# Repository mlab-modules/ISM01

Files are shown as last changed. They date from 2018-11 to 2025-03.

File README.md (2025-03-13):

# ISM01 - Si1060 EZRadioPRO Transceiver

The ISM01 is a high-performance wireless transceiver designed for long-distance data transmission. The module is based on the [Si4463 chip](https://www.silabs.com/wireless/proprietary/ezradiopro-sub-ghz-ics/device.si4463?tab=specs) from Silicon Labs, which is part of the EZRadioPRO family. With its wide frequency range and output power, it is ideal for robust and reliable wireless communication applications. 

ISM01A can operate on the open 433 or 868 MHz frequencies, which are popular in many applications.

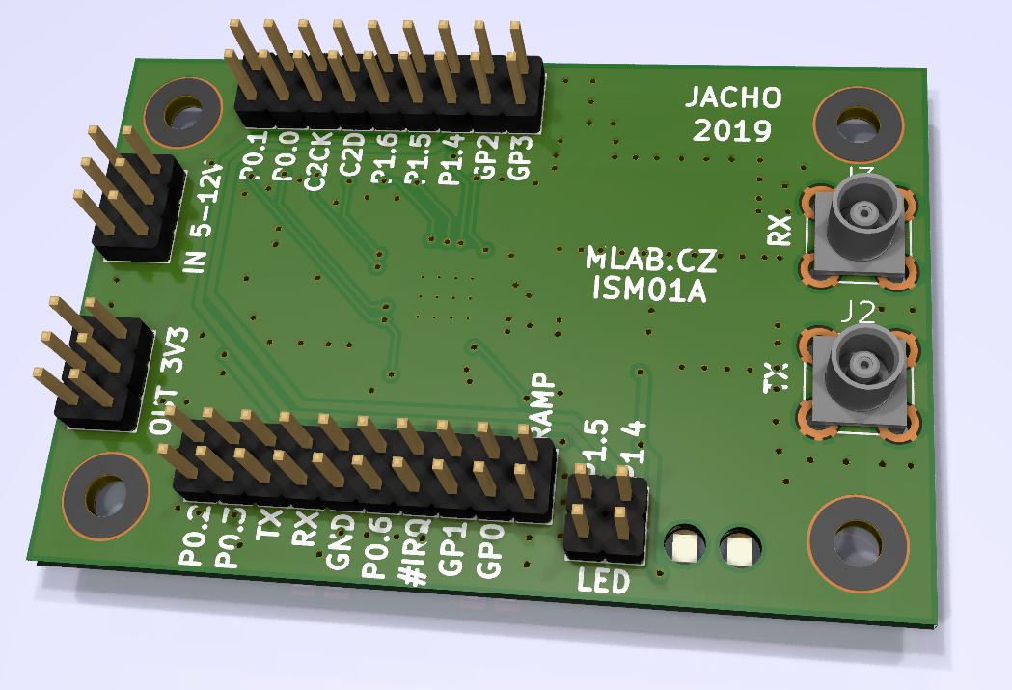
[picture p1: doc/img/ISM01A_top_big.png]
Top view on ISM01A


## Parameters

- Based on the Si1060 microcontroller integrating the Si4463 transceiver
- Chip frequency range: 142 to 1050 MHz, with the ability to operate on the open 433 or 868 MHz frequencies
- Chip output power: -20 to 20 dBm
- The Si4463 chip includes a programmable block capable of controlling radio settings and supports the SPI interface
- Power supply: 5-12V with integrated 3.3V stabilizer
- Communication: UART, SPI, GPIO
- Accessible GPIO signals directly from the transceiver
- Status indication: Two LEDs controlled from the Si chip
- Antenna connectors: MCX for RX and TX antennas. For bidirectional communication with a single antenna, connecting the [RFSWITCH module](www.mlab.cz/module/RFSWITCH01/) is recommended, which serves as an RF switch and enables MIMO 2x2 support. ISM01A can control the RFSWITCH module through GPIO pins

## Possible Applications

The MLAB ISM01A module with the Si4463 transceiver is suitable for various applications. It can be used in areas such as:

- **Remote Control**: The module can be used for wireless control of various devices, such as drones, RC cars, or home automation.
- **Data Links**: With prepared firmware, the module can function as a [SiK data communication link](https://ardupilot.org/copter/docs/common-sik-telemetry-radio.html), which can transmit [MAVLink packets](https://mavlink.io/en/). MAVLink is a protocol designed for communication with unmanned vehicles and is supported by the most widespread autopilots Ardupilot and PX4. This is ideal for applications that require wireless data transmission.
- **Wireless Sensor Networks**: The module can be used to create wireless sensor networks in IoT applications.

> Based on this module, the company [ThunderFly](https://www.thunderfly.cz) has developed a [TFSIK01](https://docs.thunderfly.cz/avionics/TFSIK01/) optimized for use on drones, which combines this ISM01A module, [RFSWITCH01](https://mlab.cz/module/RFSWITCH01/), and additional RF filters and LNA. More information about this TFSIK01 module can be found [here](https://github.com/ThunderFly-aerospace/TFSIK01/).

## Links to Related Resources

- [Silicon Labs Si4463 Product Page](https://www.silabs.com/wireless/proprietary/ezradiopro-sub-ghz-ics/device.si4463?tab=specs)
- [Si4463 Datasheet](https://www.silabs.com/documents/public/data-sheets/Si4464-63-61-60.pdf)
- [MavLink Protocol](https://mavlink.io/en/)
- [SiK Radio](https://ardupilot.org/copter/docs/common-sik-telemetry-radio.html)
- [EZRADioPRO Family](https://www.silabs.com/wireless/proprietary/ezradiopro-sub-ghz-ics)
- [TFSIK01 Module by ThunderFly](https://github.com/ThunderFly-aerospace/TFSIK01/)

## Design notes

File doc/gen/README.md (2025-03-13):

# PCB

Board size: 60.45x40.13 mm (2.38x1.58 inches)

- This is the size of the rectangle that contains the board
- Thickness: 1.6 mm (63 mils)
- Material: FR4
- Finish: HAL
- Layers: 2
- Copper thickness: 35 µm

Solder mask: TOP / BOTTOM

- Color: Green

Silk screen: TOP / BOTTOM

- Color: White

# Important sizes

Clearance: 0.2 mm (8 mils)

Track width: 0.2 mm (8 mils)

- By design rules: 0.2 mm (8 mils)

Drill: 0.3 mm (12 mils)

- Vias: 0.5 mm (20 mils) [Design: 0.4 mm (16 mils)]
- Pads: 0.3 mm (12 mils)
- The above values are real drill sizes, they add 0.1 mm (4 mils) to plated holes (PTH)

Via: 0.8/0.4 mm (31/16 mils)

- By design rules: 0.4/0.3 mm (16/12 mils)
- Micro via: yes [0.2/0.1 mm (8/4 mils)]
- Buried/blind via: yes
- Total: 129 (thru: 129 buried/blind: 0 micro: 0)

Outer Annular Ring: 0.1 mm (4 mils)

- By design rules: 0.1 mm (4 mils)

Eurocircuits class: 6D
- Using min drill 0.25 mm for an OAR of 0.13 mm

# General stats

Components count: (SMD/THT)

- Top: 0/29 (THT)
- Bottom: 67/2 (SMD + THT)

Defined tracks:

- 0.2 mm (8 mils)
- 0.3 mm (12 mils)
- 0.4 mm (16 mils)
- 0.5 mm (20 mils)
- 0.5 mm (20 mils)
- 0.6 mm (24 mils)
- 0.8 mm (31 mils)
- 0.86 mm (34 mils)

Used tracks:

- 0.2 mm (8 mils) (194) defined: yes
- 0.3 mm (12 mils) (16) defined: yes
- 0.5 mm (20 mils) (175) defined: yes
- 0.86 mm (34 mils) (48) defined: yes

Defined vias:

- 0.8/0.4 mm (31/16 mils)

Used vias:

- 0.8/0.4 mm (31/16 mils) (Count: 129, Aspect: 2.0 A) defined: yes

Holes (excluding vias):

- 0.2 mm (8 mils) (12)
- 0.89 mm (35 mils) (54)
- 1.5 mm (59 mils) (2)
- 1.7 mm (67 mils) (8)
- 2.7 mm (106 mils) (2)
- 3.0 mm (118 mils) (4)

Oval holes:

Drill tools (including vias and computing adjusts and rounding):

- 0.3 mm (12 mils) (12)
- 0.5 mm (20 mils) (129)
- 1.0 mm (39 mils) (54)
- 1.6 mm (63 mils) (2)
- 1.8 mm (71 mils) (8)
- 2.7 mm (106 mils) (2)
- 3.1 mm (122 mils) (4)

Solder paste stats:

Using a paste with 87.75 % alloy, that has an specific gravity for the alloy of 7.4 g/cm³
and 1.0 g/cm³ for the flux. This paste has an specific gravity of  4.15 g/cm³.

The stencil thickness is  0.12 mm.

| Side | Pads with paste | Area [mm²] | Paste [g] |
|---|---|---|---|
| Total  | 185 | 208.88 | 1.04 |

Note: this is just an approximation to the theoretical value. Margins of the solder mask and waste aren't computed.

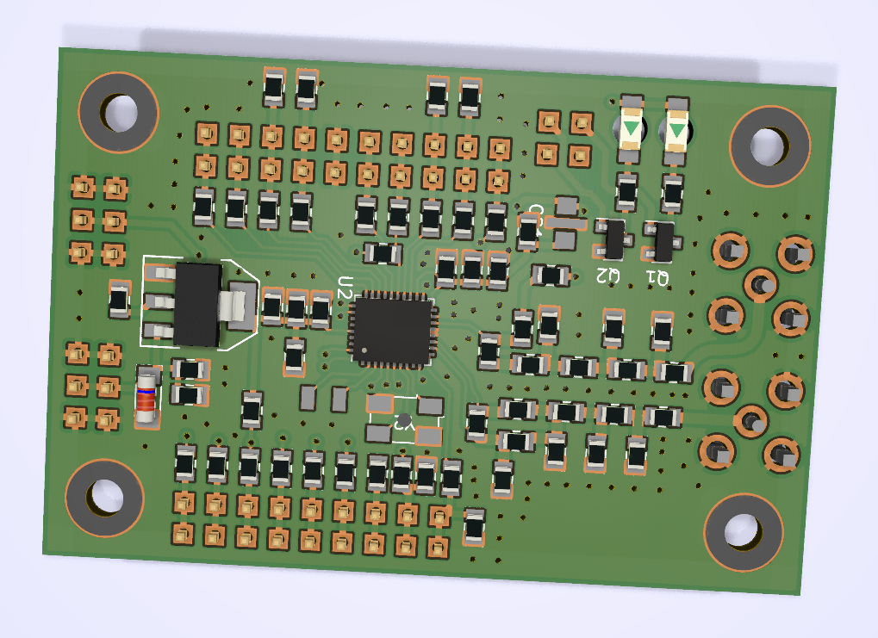
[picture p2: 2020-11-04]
doc/img/ISM01A_bot_big.png

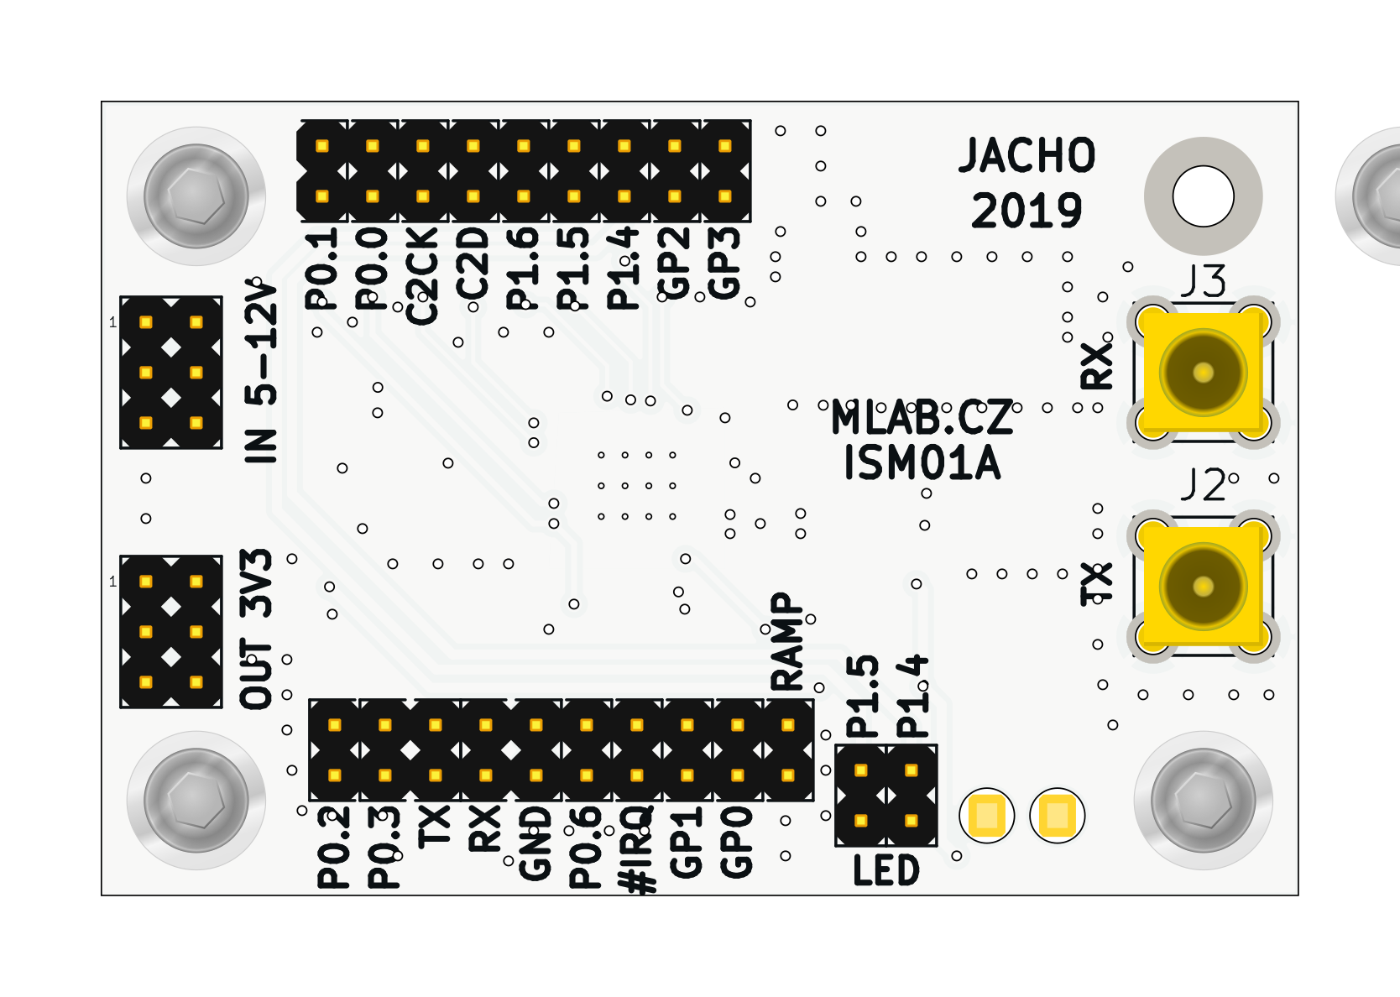
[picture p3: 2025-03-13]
doc/gen/img/ISM01-top.png

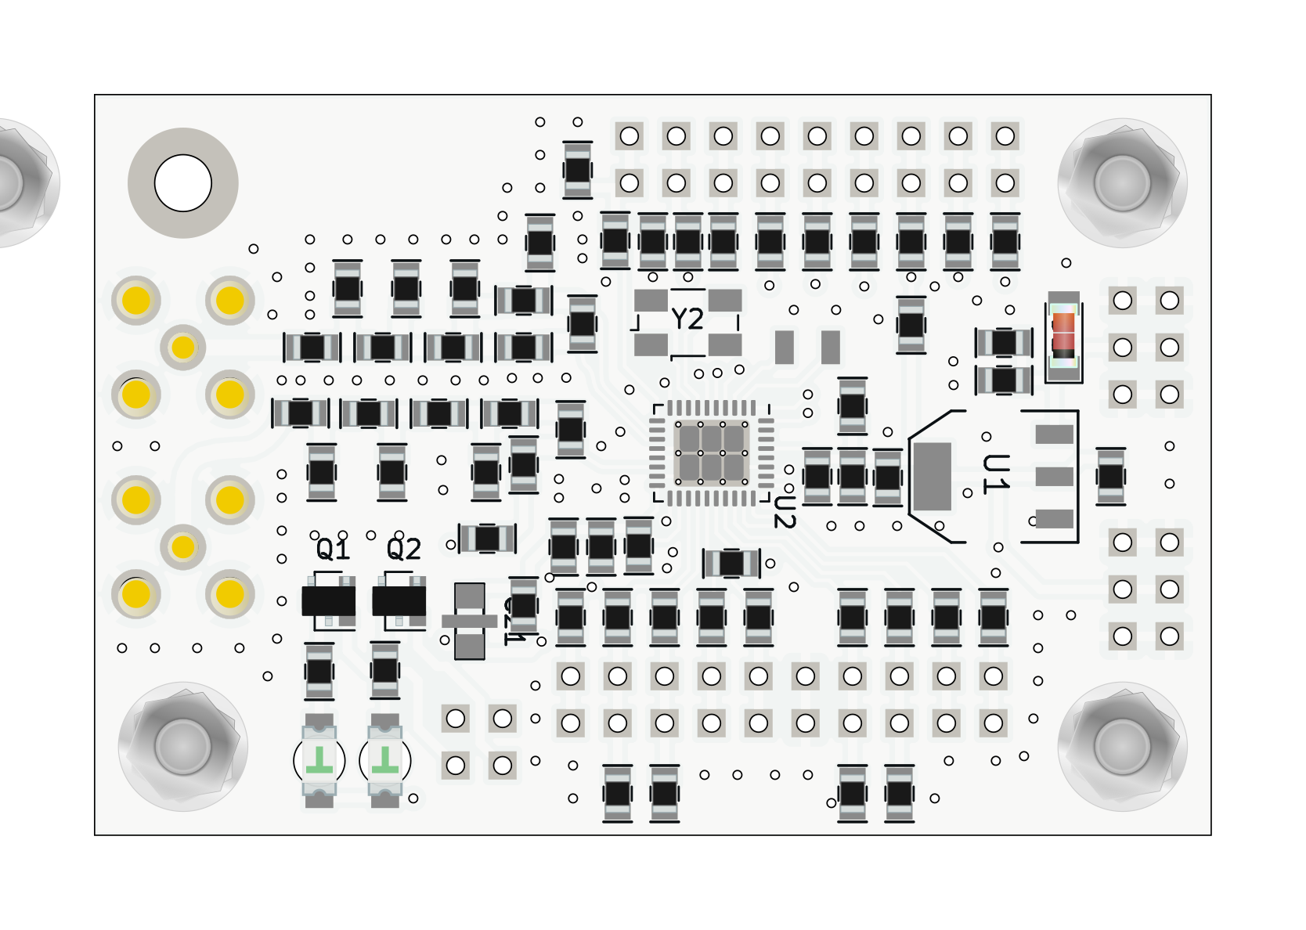
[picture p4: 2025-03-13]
doc/gen/img/ISM01-bottom.png

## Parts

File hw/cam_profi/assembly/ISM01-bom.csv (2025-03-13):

Component | Description | Part | References | Value | Footprint | Quantity Per PCB | Datasheet | ust_id
1 |  | C_Small | C12 | 2.7pF | SMD-0805 | 1 |  | 5c70984712875079b91f8b28
2 |  | C_Small | C13 | 5.1pF | SMD-0805 | 1 |  | 5c70984812875079b91f8ba2
3 |  | C_Small | C4C6 | 6.8pf | SMD-0805 | 2 |  | 5c70984712875079b91f8b2e
4 |  | C_Small | C7C8 | 15pF | SMD-0805 | 2 |  | 5c70984712875079b91f8b32
5 |  | C_Small | C15 | 33pF | SMD-0805 | 1 |  | 5c70984712875079b91f8b37
6 |  | C_Small | C9C10C11 | 8,2pF | SMD-0805 | 3 |  | 5c70984712875079b91f8b2f
7 |  | C_Small | C17 | 100pF | SMD-0805 | 1 |  | 5c70984712875079b91f8b3b
8 |  | C_Small | C14C22C23C25C26C27C28 | 10nF | SMD-0805 | 7 |  | 5c70984712875079b91f8b49
9 |  | C_Small | C2C16C19 | 100nF | SMD-0805 | 3 |  | 5c70984712875079b91f8b4c
10 |  | C_Small | C1C3C5C18C20 | 10uF | SMD-0805 | 5 |  | 5c70984812875079b91f8bbd
11 |  | EMI_Filter_C | C21 | NFM21PC105 | FIR1 | 1 | http://www.murata.com/~/media/webrenewal/support/library/catalog/products/emc/emifil/c31e.ashx?la=en-gb
12 |  | LED | D3 | GREEN | LED_1206 | 1 |  | 5c70984412875079b91f8895
13 |  | D_ZENER | D1 | M4 | Diode-MiniMELF_Standard | 1 |  | 5c70984512875079b91f88ac
14 |  | LED | D2 | RED | LED_1206 | 1 |  | 5c70984412875079b91f8896
15 |  | HEADER_1x02 | J24J25 | HEADER_1x02 | Straight_1x02 | 2
16 |  | HEADER_2x01_PARALLEL | J6J7J8J9J10J11J12J13J14J15J16J17J18J19J20J21J22J23J26 | HEADER_2x01_PARALLEL | Straight_2x01 | 19
17 |  | JUMP_3X2 | J1J4 | JUMP_3X2 | Straight_2x03 | 2
18 |  | SMA | J2J3 | SMA | SMA6251A13G50 | 2 |  | 5c70984412875079b91f87ac
19 |  | L_Small | L1L2 | 0R | SMD-0805 | 2 |  | 5c70984512875079b91f896b
20 |  | L_Small | L3L4L5L6 | 18nH | SMD-0805 | 4 |  | 5c70984412875079b91f8806
21 |  | L_Small | L7 | 39nH | SMD-0805 | 1 |  | 5c70984412875079b91f8809
22 |  | L_Small | L9L10 | 56nH | SMD-0805 | 2 |  | 5c70984812875079b91f8ba4
23 |  | L_Small | L8 | 220nH | SMD-0805 | 1 |  | 5c70984412875079b91f880d
24 |  | Q_NPN_BEC | Q1Q2 | BC817 | SOT-23 | 2 |  | 5c70984712875079b91f8aec
25 |  | R | R1R21 | 0R | SMD-0805 | 2 |  | 5c70984512875079b91f896b
26 |  | R | R2R3R4R5R6R7R8R9R10R11R12R13R14R15R16R17R18R19 | 33R | SMD-0805 | 18 |  | 5c70984512875079b91f8970
27 |  | R | R22R23 | 150R | SMD-0805 | 2 |  | 5c70984512875079b91f897a
28 |  | R | R20 | 1k | SMD-0805 | 1 |  | 5c70984512875079b91f898c
29 |  | LM1117 | U1 | LM1117-3V3 | SOT-223 | 1 |  | 5c70984712875079b91f8af9
30 |  | Si1060-A-GM | U2 | Si1060-A-GM | QFN-36-1EP_5x6mm_P0.5mm_EP3.6x4.1mm_ThermalVias | 1 | https://www.silabs.com/documents/public/data-sheets/Si106x-8x.pdf | 5c70984812875079b91f8ba3
31 |  | Crystal_GND24 | Y2 | ABM3B-30.000MHZ-10-1-U-T | Crystal_SMD_Abracon_ABM3B-4Pin_5.0x3.2mm | 1 |  | 5c70984712875079b91f8ba1
32 |  | Crystal | Y1 | ABS07-120-32.768KHZ | ABS07 | 1 |  | 5c70984712875079b91f8b1b

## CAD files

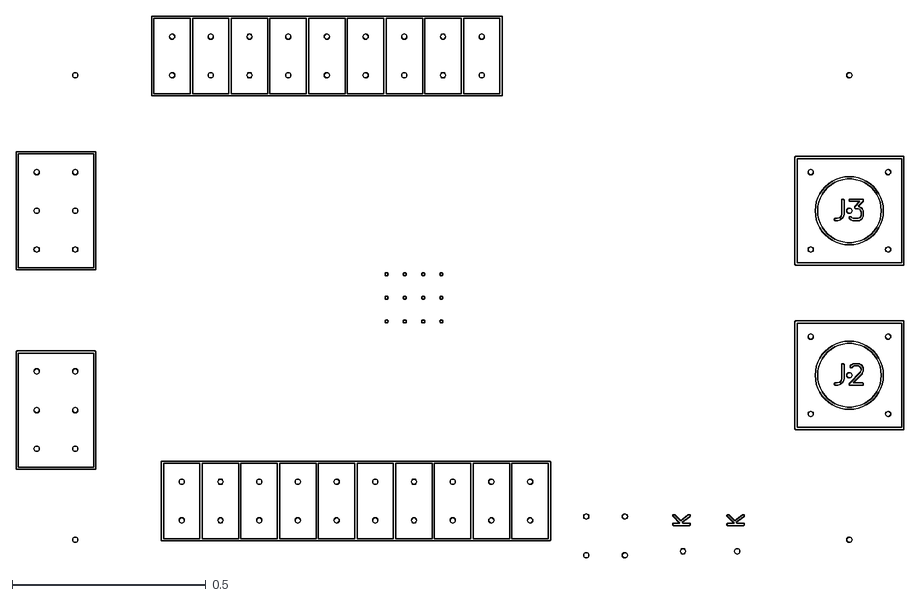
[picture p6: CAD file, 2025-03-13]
doc/gen/dxf/ISM01-F_Fab.dxf
2.29 x 1.40

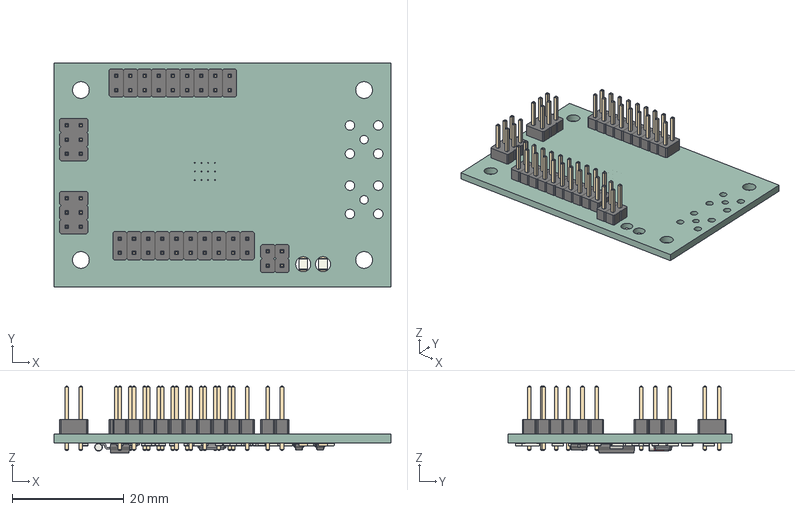
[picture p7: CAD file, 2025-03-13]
doc/gen/ISM01.step
60.5 x 40.1 x 11.9 mm
PinHeader_2x01_P254mm_Vertical x 19
PinHeader_1x02_P254mm_Vertical x 2
PinHeader_2x03_P254mm_Vertical x 2
R_0805_2012Metric x 59
SOT_223
SOT_23 x 2
LED_1206_3216Metric x 2
D_MiniMELF_Standard
Crystal_SMD_Abracon_ABM3B-4Pin_5.0x3.2mm
kibot_3q4dxw63_PCB

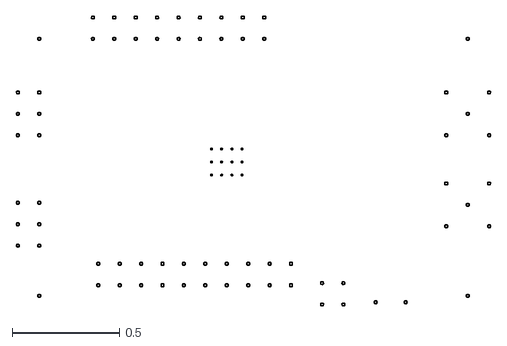
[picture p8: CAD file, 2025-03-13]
doc/gen/dxf/ISM01-Margin.dxf
2.21 x 1.35

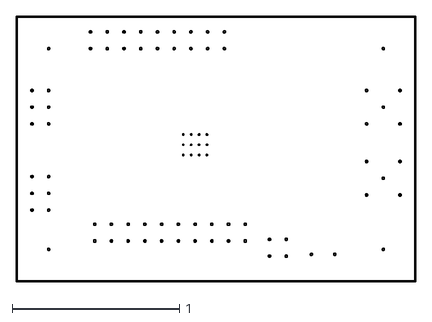
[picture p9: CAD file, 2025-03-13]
doc/gen/dxf/ISM01-Edge_Cuts.dxf
2.39 x 1.59

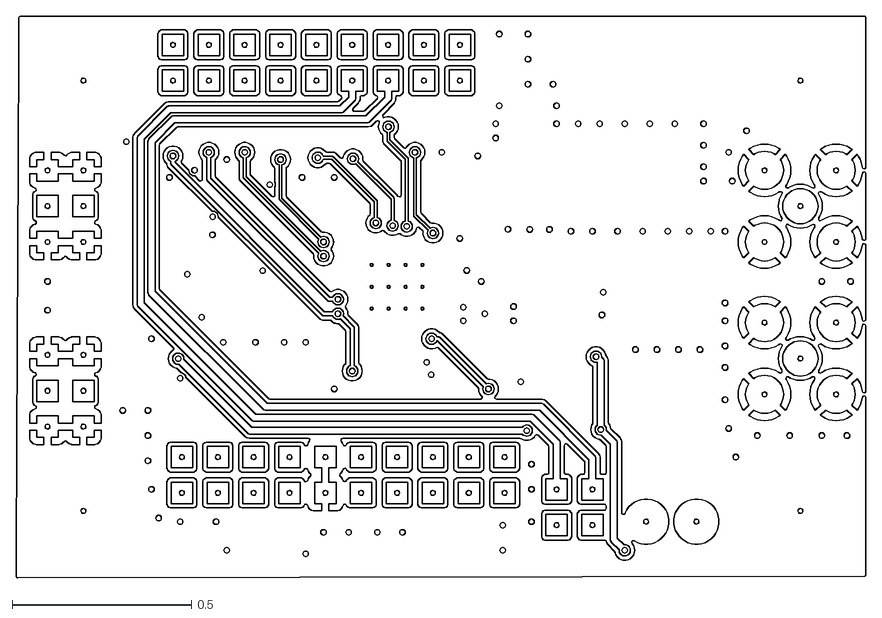
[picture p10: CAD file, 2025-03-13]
doc/gen/dxf/ISM01-F_Cu.dxf
2.37 x 1.57

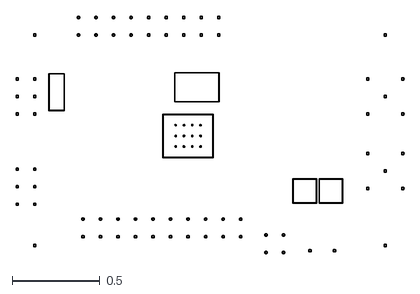
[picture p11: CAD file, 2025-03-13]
doc/gen/dxf/ISM01-B_Courtyard.dxf
2.21 x 1.35

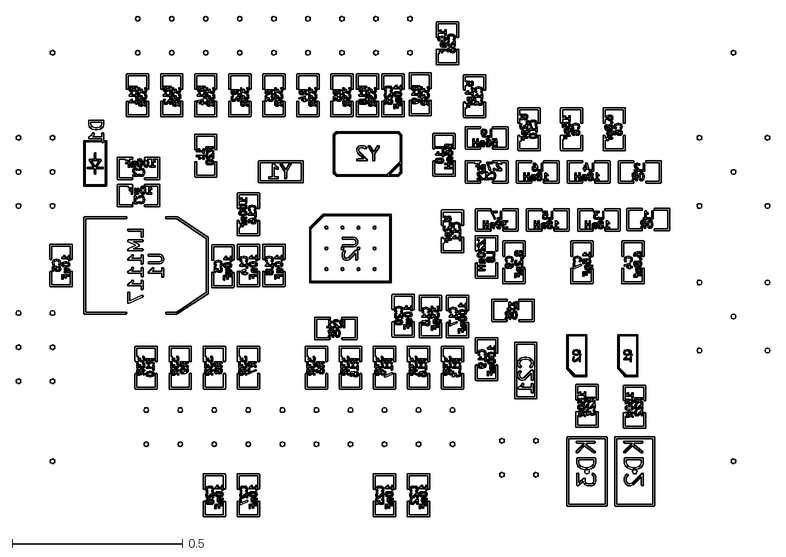
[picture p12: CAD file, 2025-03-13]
doc/gen/dxf/ISM01-B_Fab.dxf
2.21 x 1.47

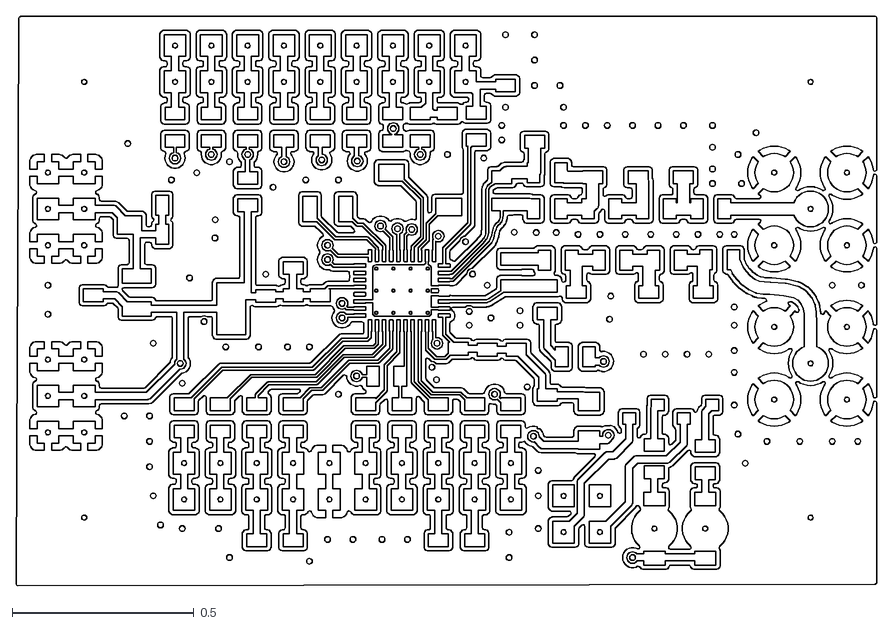
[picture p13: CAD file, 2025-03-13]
doc/gen/dxf/ISM01-B_Cu.dxf
2.37 x 1.57

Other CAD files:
doc/gen/dxf/ISM01-B_Mask.dxf
doc/gen/dxf/ISM01-B_Paste.dxf
doc/gen/dxf/ISM01-B_Silkscreen.dxf
doc/gen/dxf/ISM01-F_Mask.dxf
doc/gen/dxf/ISM01-F_Silkscreen.dxf

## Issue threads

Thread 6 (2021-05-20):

Inappropriate RC filters at IO signals

kaklik, 2021-05-20:
IO signals are loaded by RC filter with values 33Ohm and 10nF!

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

The value of the capacitors should be decreased to about 100pF or completely removed.

-------

Objevení tého chyby trvalo více než dva roky.   Zásadní roli zde zřejmě hrálo umístění kondenzátorů ve schéma do místa, kde nikdo neočekával souvislost s IO signály.  Tím pádem nikdo z řešitelů nezohledňoval přítomnost kapacit při řešení nefuknčnosti modemu na 3.3V IO signalizaci.   V průběhu celé doby byl tento problém řešen použitím 5V signalizace na modemu napájeném z 3.3V.
Toto nešťastné rozhodnutí zas souvisí s podivnou formulací z datasheetu Si1060.

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

kaklik, 2021-05-20:
@ChroustJan  Očekával bych že svojí chybu napravíš a až potom si odebereš přiřazení..

ChroustJan, 2021-05-21:
@kaklik chceš tam nic nebo 100pF?

kaklik, 2021-05-22:
Právě se mi podařilo v ISM01A přepsat firmware při USB-UART převodníku přepuntém na 3.3V logiku.

    $ ./uploader.py --port /dev/ttyUSB0 radio.ism01a.ihx
    uploading to port /dev/ttyUSB0
    Connecting to /dev/ttyUSB0
    Trying autosync

    +++�	_3DmbH��	`3DmbF�OK
    ATI

    ATI
    RFD SiK 2.0 on
    AT&UPDATE
    Sent update command
    Got sync
    board 4f  freq 43
    erasing...
    programing...
    [##################################################] 45424/45424 (100%)

    verifying...
    [##################################################] 45424/45424 (100%)

    done.

Zároveň modem rozumí AT příkazům.

    $ picocom -b 57600 /dev/ttyUSB0
    picocom v2.2

    port is        : /dev/ttyUSB0
    flowcontrol    : none
    baudrate is    : 57600
    parity is      : none
    databits are   : 8
    stopbits are   : 1
   escape is      : C-a
   local echo is  : no
   noinit is      : no
   noreset is     : no
   nolock is      : no
   send_cmd is    : sz -vv
   receive_cmd is : rz -vv -E
   imap is        :
   omap is        :
   emap is        : crcrlf,delbs,

   Type [C-a] [C-h] to see available commands

   Terminal ready
   ATI0
   RFD SiK 2.0 on ISM01A

Udělal jsem to tak, že jsem odletoval kondezátory C22, C23, C25, C26, C27, C28.

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

Použít kapacity s malou hodnotou jsem nezkoušel, protože je nemám.

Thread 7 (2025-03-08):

si1060  disuse

lv333ming, 2025-03-08:
The si1060 IC has been officially phased out. Is there any plan to use the latest model?

kaklik, 2025-03-08:
> The si1060 IC has been officially phased out. Is there any plan to use the latest model?

Hi, yes, I know that, but there seem to be plenty of those chips in stock.
What IC type do you mean by the "latest model"?

lv333ming, 2025-03-09:
> > si1060 IC已正式停产。有没有计划使用最新型号？
>
> 你好，是的，我知道，但这些芯片似乎库存充足。 你说的“最新型号”是指哪种 IC 类型？

I haven’t found a suitable replacement model for the Si1060 either

lv333ming, 2025-03-09:
> > The si1060 IC has been officially phased out. Is there any plan to use the latest model?
>
> Hi, yes, I know that, but there seem to be plenty of those chips in stock. What IC type do you mean by the "latest model"?

I haven’t found a suitable replacement model for the Si1060 either

kaklik, 2025-03-09:
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

SiliconLabs suggests replacing the Si1060 with [EFR32FG23B020F128GM40](https://www.silabs.com/wireless/proprietary/efr32fg23-sub-ghz-wireless-soc/device.efr32fg23b020f128gm40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). Making the new version of hardware ISM module is quite straightforward.  The biggest challenge is the adaptation of the firmware, because
EFR32FG23B020F128GM40 is ARM Cortex-M33 core-based architecture.

lv333ming, 2025-03-13:
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

can try using an artificial intelligence system to assist in solving the code generation problem. This is my personal suggestion.

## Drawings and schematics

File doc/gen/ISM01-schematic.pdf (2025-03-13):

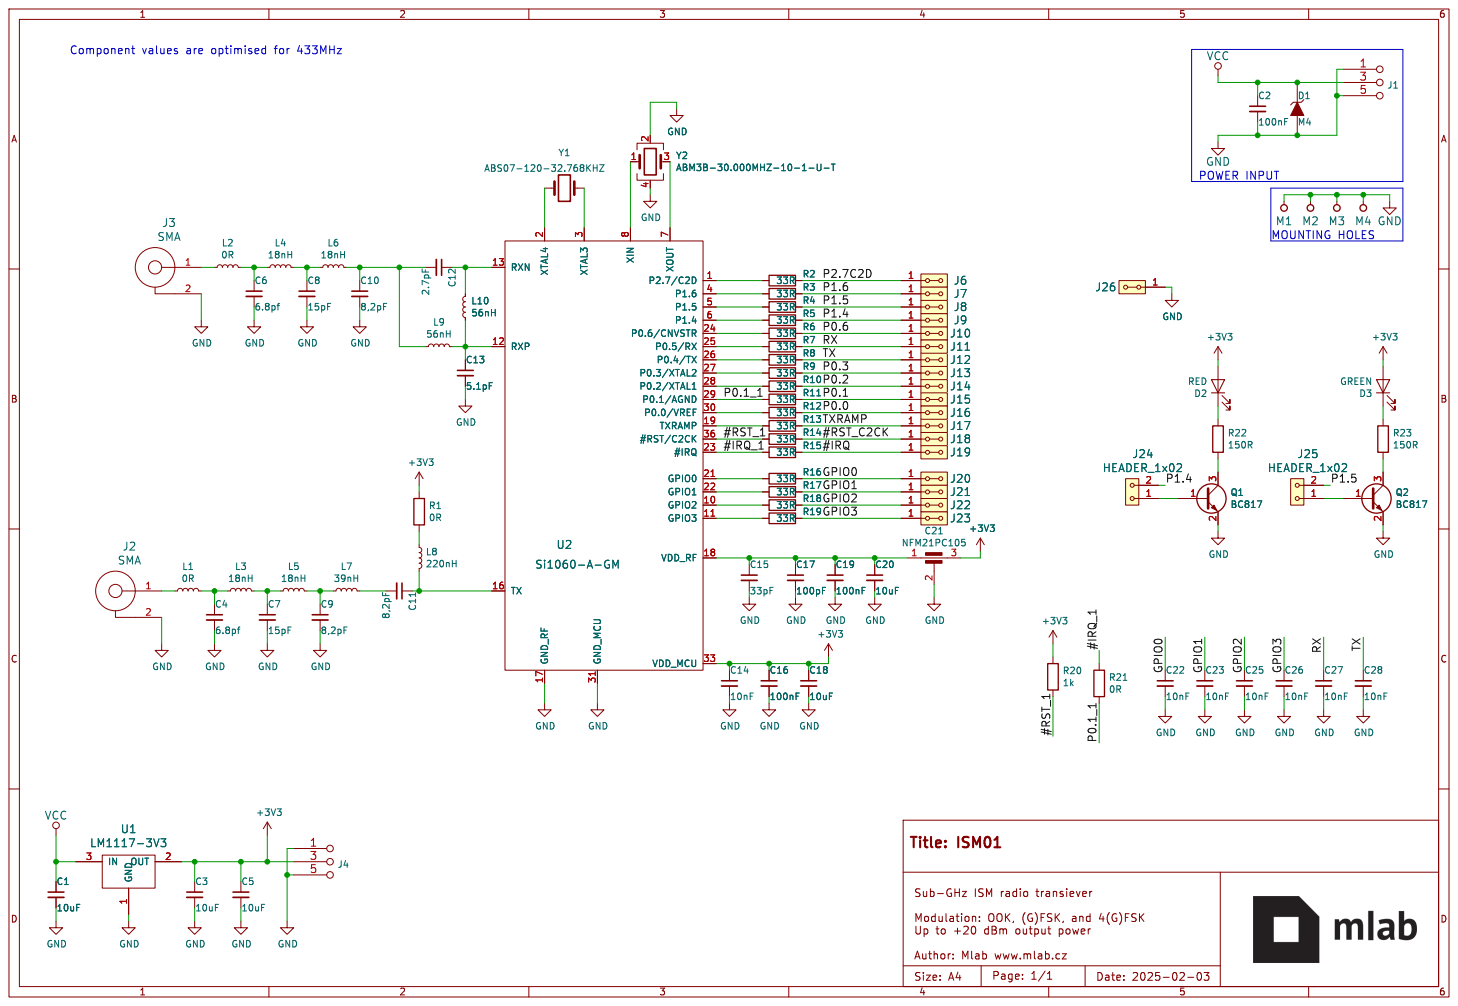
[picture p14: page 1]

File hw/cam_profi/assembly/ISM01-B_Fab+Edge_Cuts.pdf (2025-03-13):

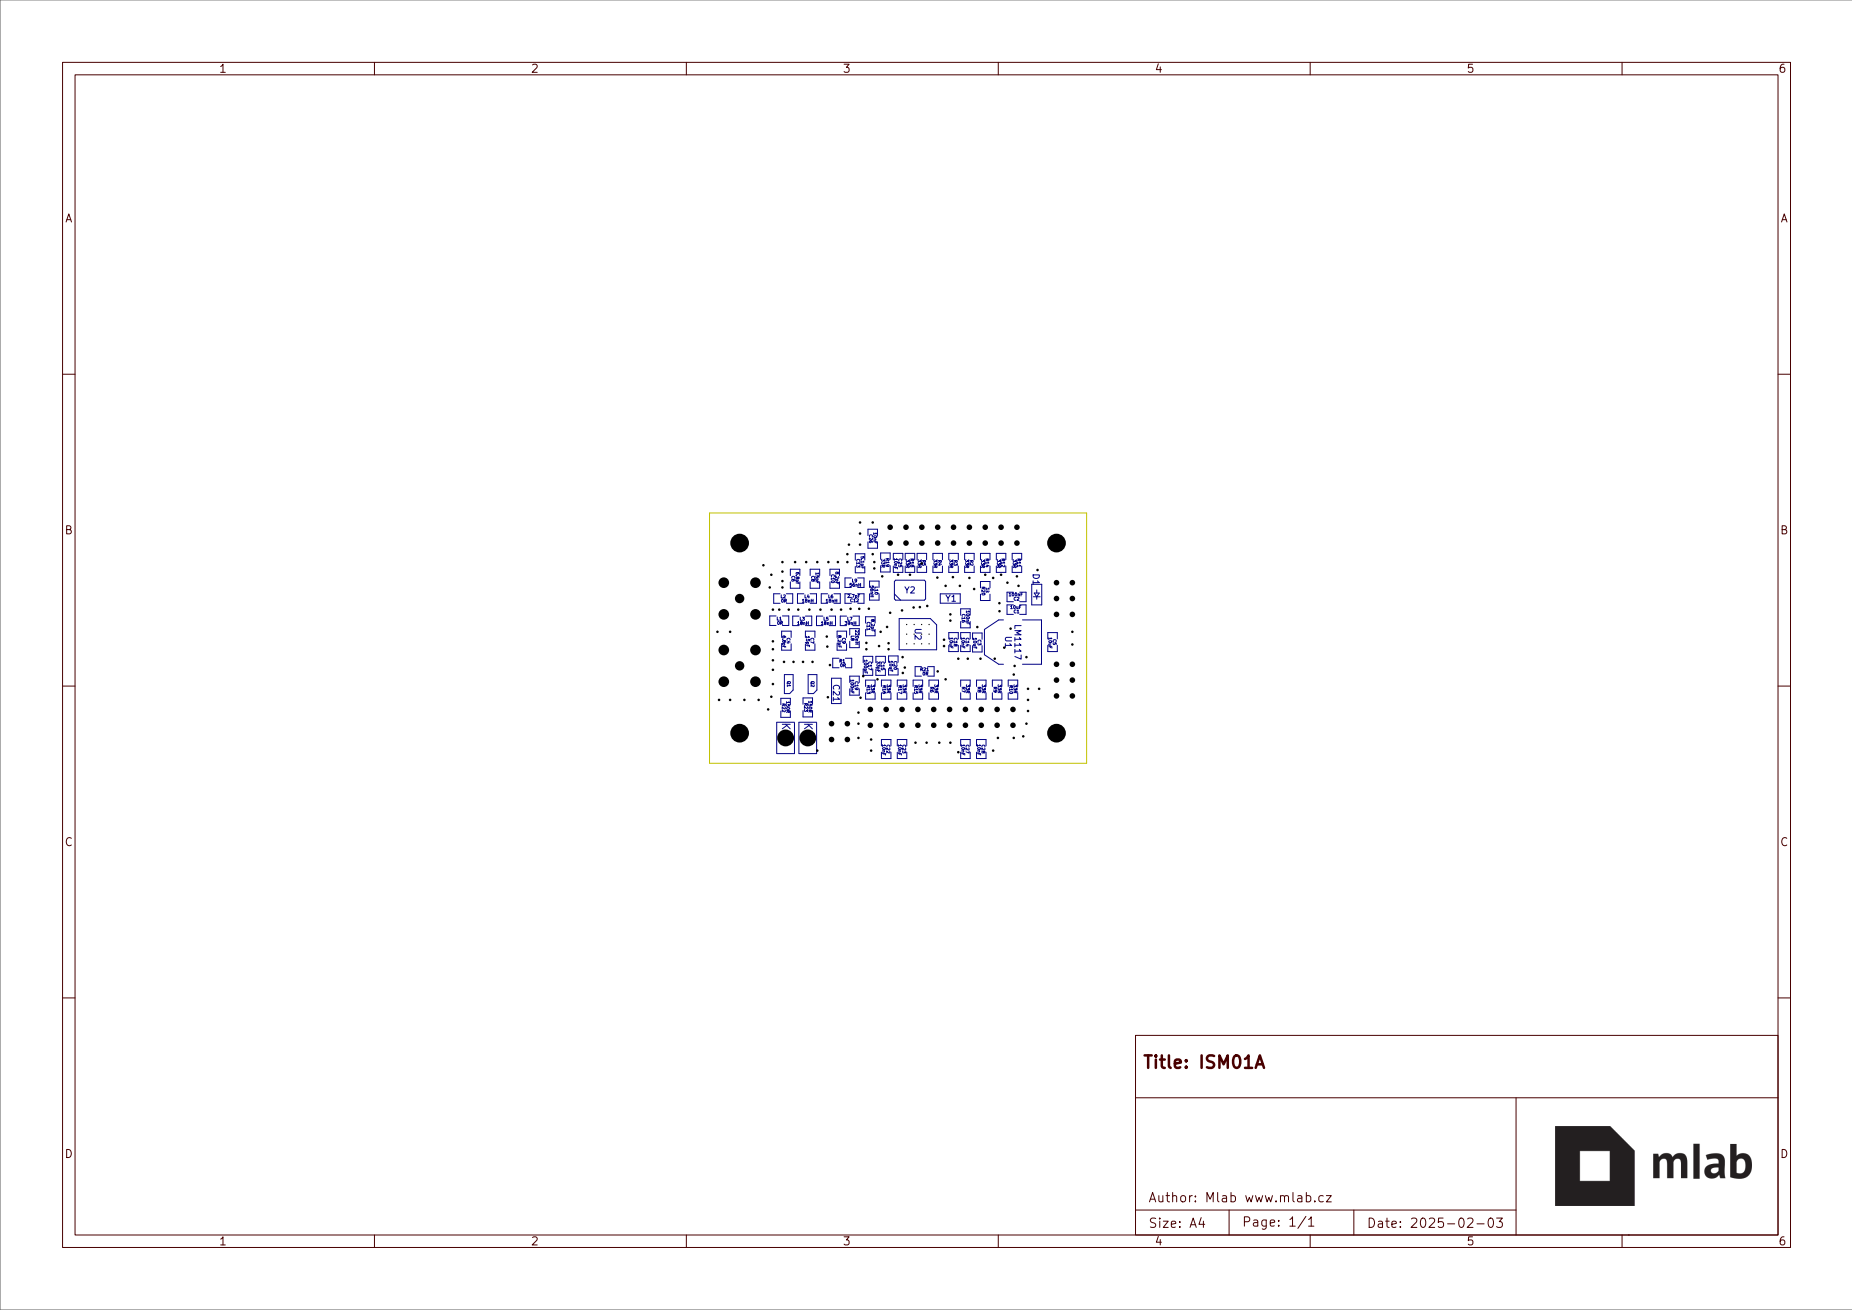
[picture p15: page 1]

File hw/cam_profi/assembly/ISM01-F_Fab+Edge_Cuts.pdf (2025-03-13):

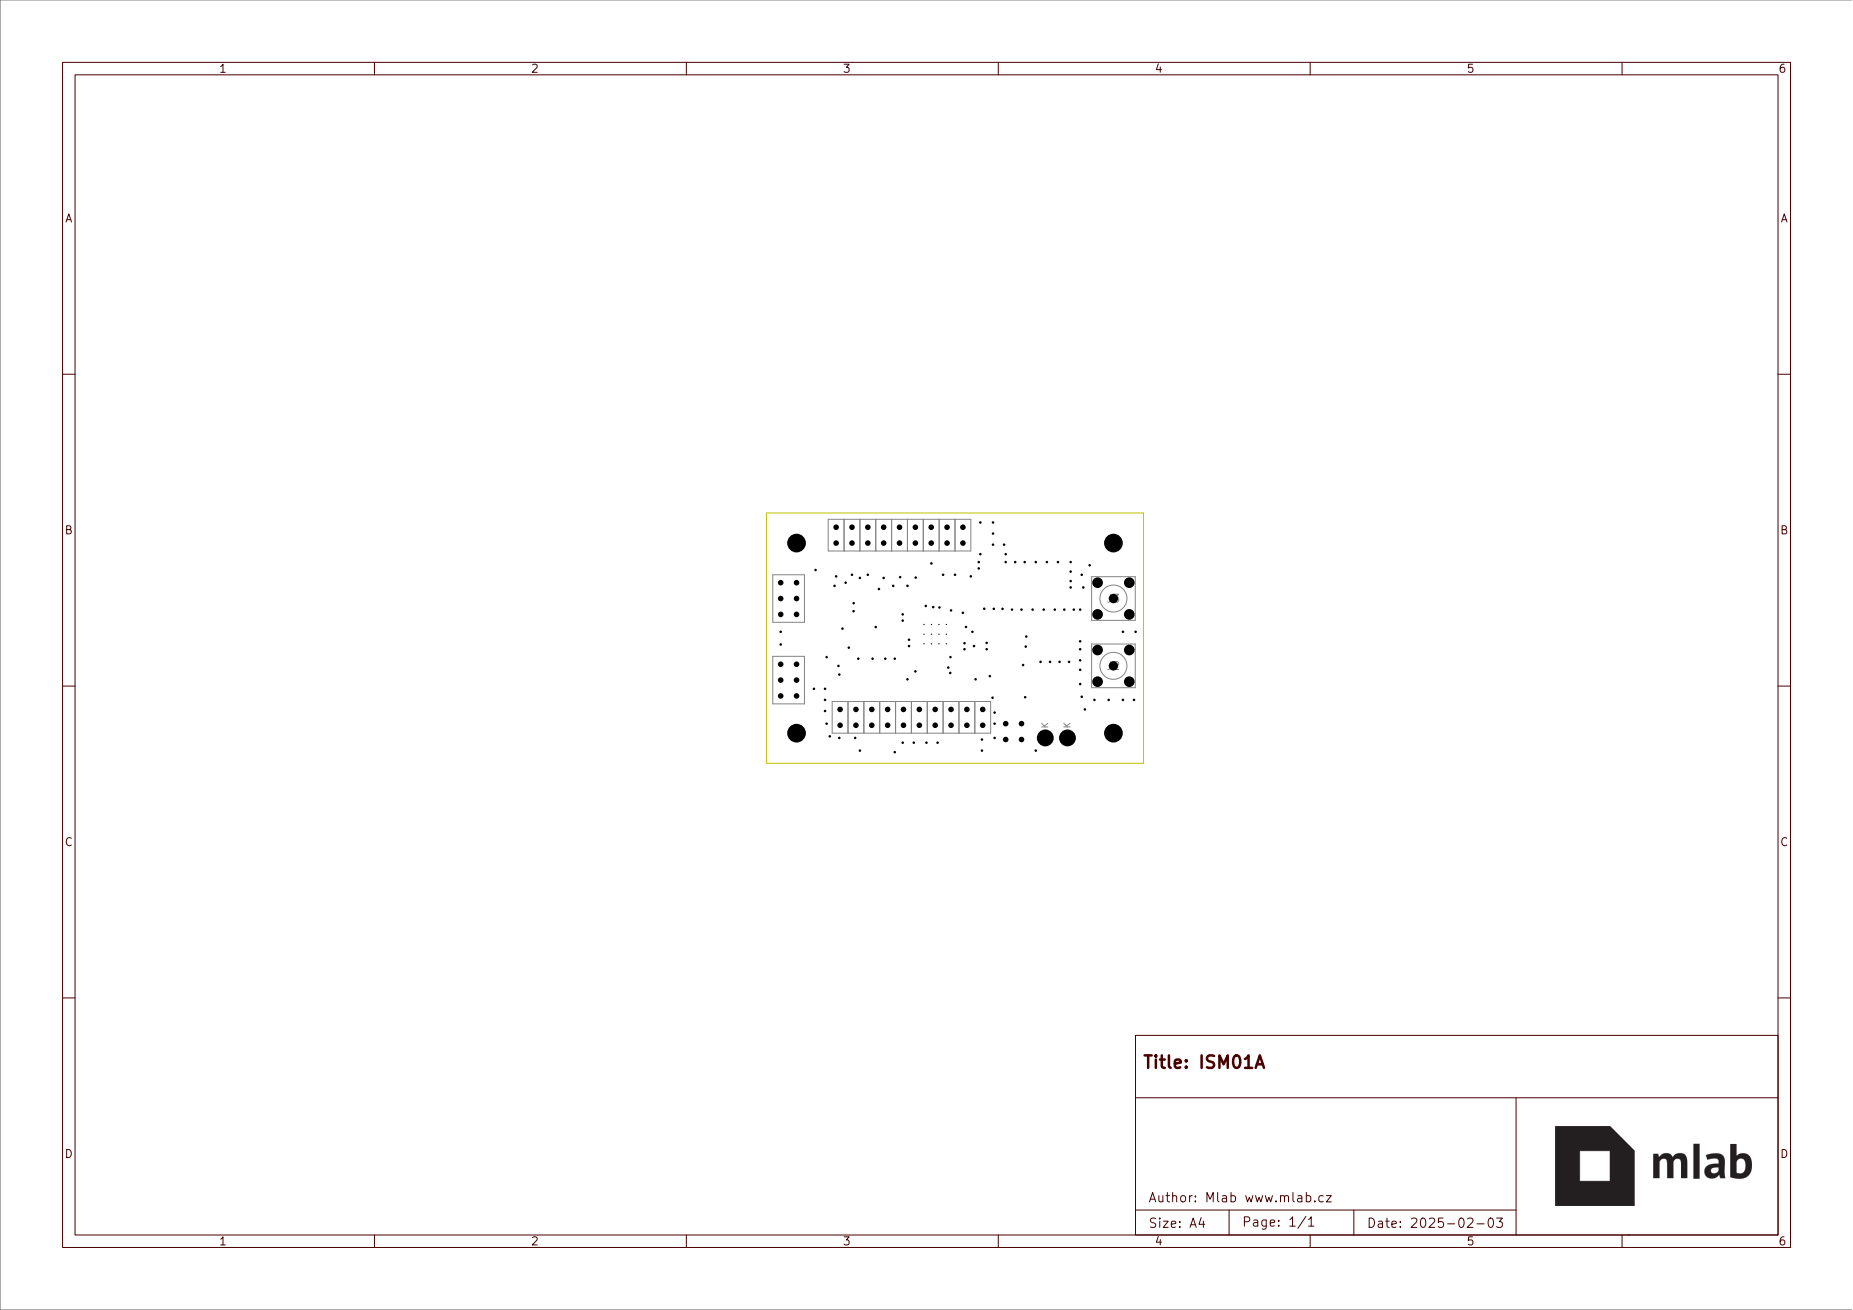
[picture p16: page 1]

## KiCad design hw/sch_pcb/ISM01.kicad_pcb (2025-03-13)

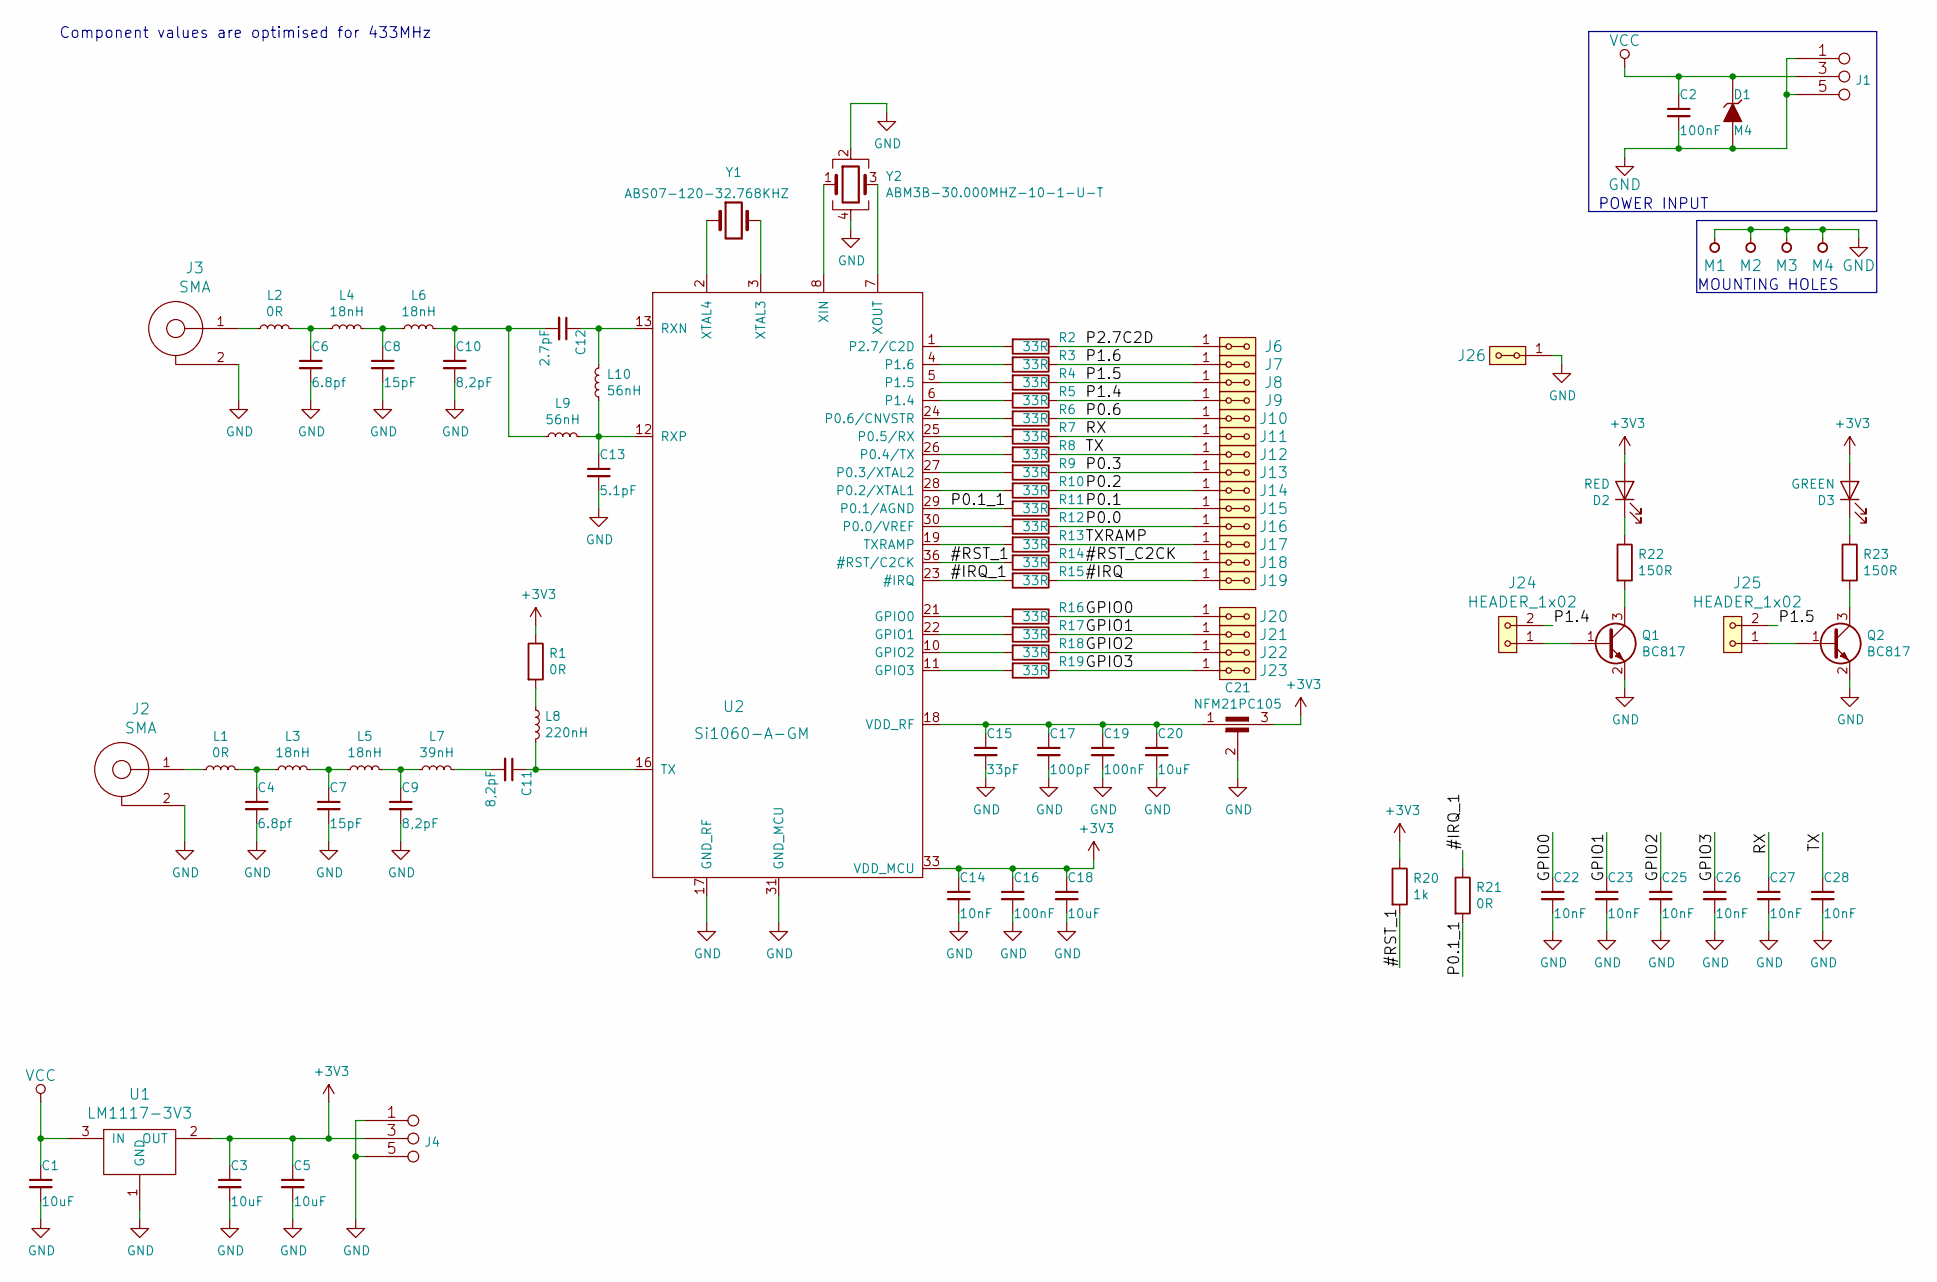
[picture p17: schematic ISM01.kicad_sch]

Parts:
C1, C3, C5, C18, C20: 10uF; SMD-0805
C2, C16, C19: 100nF; SMD-0805
C4, C6: 6.8pf; SMD-0805
C7, C8: 15pF; SMD-0805
C9, C10, C11: 8,2pF; SMD-0805
C12: 2.7pF; SMD-0805
C13: 5.1pF; SMD-0805
C14, C22, C23, C25, C26, C27, C28: 10nF; SMD-0805
C15: 33pF; SMD-0805
C17: 100pF; SMD-0805
C21: NFM21PC105; FIR1
D1: M4; Diode-MiniMELF_Standard
D2: RED; LED_1206
D3: GREEN; LED_1206
J1, J4: JUMP_3X2; Straight_2x03
J2, J3: SMA; SMA6251A13G50
J6, J7, J8, J9, J10, J11, J12, J13, J14, J15, J16, J17, J18, J19, J20, J21, J22, J23, J26: HEADER_2x01_PARALLEL; Straight_2x01
J24, J25: HEADER_1x02; Straight_1x02
L1, L2: 0R; SMD-0805
L3, L4, L5, L6: 18nH; SMD-0805
L7: 39nH; SMD-0805
L8: 220nH; SMD-0805
L9, L10: 56nH; SMD-0805
M1, M2, M3, M4: HOLE; MountingHole_3mm
Q1, Q2: BC817; SOT-23
R1, R21: 0R; SMD-0805
R2, R3, R4, R5, R6, R7, R8, R9, R10, R11, R12, R13, R14, R15, R16, R17, R18, R19: 33R; SMD-0805
R20: 1k; SMD-0805
R22, R23: 150R; SMD-0805
U1: LM1117-3V3; SOT-223
U2: Si1060-A-GM; QFN-36-1EP_5x6mm_P0.5mm_EP3.6x4.1mm_ThermalVias
Y1: ABS07-120-32.768KHZ; ABS07
Y2: ABM3B-30.000MHZ-10-1-U-T; Crystal_SMD_Abracon_ABM3B-4Pin_5.0x3.2mm

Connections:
+3V3: C3.1, C5.1, C14.1, C16.1, C18.1, C21.3, D2.2 (A), D3.2 (A), J4.3 (4), J4.4, R1.1, R20.1, U1.2 (OUT), U1.4 (OUT), U2.33 (VDD_MCU)
/#IRQ: J19.1, J19.2, R15.1
/#IRQ_1: R15.2, R21.1, U2.23 (#IRQ)
/#RST_1: R14.2, R20.2, U2.36 (#RST/C2CK)
/#RST_C2CK: J18.1, J18.2, R14.1
/GPIO0: C22.1, J20.1, J20.2, R16.1
/GPIO1: C23.1, J21.1, J21.2, R17.1
/GPIO2: C25.1, J22.1, J22.2, R18.1
/GPIO3: C26.1, J23.1, J23.2, R19.1
/P0.0: J16.1, J16.2, R12.1
/P0.1: J15.1, J15.2, R11.1
/P0.1_1: R11.2, R21.2, U2.29 (P0.1/AGND)
/P0.2: J14.1, J14.2, R10.1
/P0.3: J13.1, J13.2, R9.1
/P0.6: J10.1, J10.2, R6.1
/P1.4: J9.1, J9.2, J24.2, R5.1
/P1.5: J8.1, J8.2, J25.2, R4.1
/P1.6: J7.1, J7.2, R3.1
/P2.7C2D: J6.1, J6.2, R2.1
/RX: C27.1, J11.1, J11.2, R7.1
/TX: C28.1, J12.1, J12.2, R8.1
/TXRAMP: J17.1, J17.2, R13.1
GND: C1.2, C2.2, C3.2, C4.2, C5.2, C6.2, C7.2, C8.2, C9.2, C10.2, C13.2, C14.2, C15.2, C16.2, C17.2, C18.2, C19.2, C20.2, C21.2, C22.2, C23.2, C25.2, C26.2, C27.2, C28.2, D1.2 (A), J1.1 (2), J1.2, J1.5 (6), J1.6, J2.2, J3.2, J4.1 (2), J4.2, J4.5 (6), J4.6, J26.1, J26.2, M1.1, M2.1, M3.1, M4.1, Q1.2 (E), Q2.2 (E), U1.1 (GND), U2.9 (GND_RF), U2.14 (GND_RF), U2.15 (GND_RF), U2.17 (GND_RF), U2.31 (GND_MCU), U2.37 (GND_RF), Y2.2, Y2.4
unnamed: C4.1, L1.2, L3.1
unnamed: C6.1, L2.2, L4.1
unnamed: C7.1, L3.2, L5.1
unnamed: C8.1, L4.2, L6.1
unnamed: C9.1, L5.2, L7.1
unnamed: C10.1, C12.2, L6.2, L9.1
unnamed: C11.1, L8.2, U2.16 (TX)
unnamed: C11.2, L7.2
unnamed: C12.1, L10.2, U2.13 (RXN)
unnamed: C13.1, L9.2, L10.1, U2.12 (RXP)
unnamed: C15.1, C17.1, C19.1, C20.1, C21.1, U2.18 (VDD_RF), U2.20 (VDD_RF)
unnamed: D2.1 (K), R22.1
unnamed: D3.1 (K), R23.1
unnamed: J2.1, L1.1
unnamed: J3.1, L2.1
unnamed: J24.1, Q1.1 (B)
unnamed: J25.1, Q2.1 (B)
unnamed: L8.1, R1.2
unnamed: Q1.3 (C), R22.2
unnamed: Q2.3 (C), R23.2
unnamed: R2.2, U2.1 (P2.7/C2D)
unnamed: R3.2, U2.4 (P1.6)
unnamed: R4.2, U2.5 (P1.5)
unnamed: R5.2, U2.6 (P1.4)
unnamed: R6.2, U2.24 (P0.6/CNVSTR)
unnamed: R7.2, U2.25 (P0.5/RX)
unnamed: R8.2, U2.26 (P0.4/TX)
unnamed: R9.2, U2.27 (P0.3/XTAL2)
unnamed: R10.2, U2.28 (P0.2/XTAL1)
unnamed: R12.2, U2.30 (P0.0/VREF)
unnamed: R13.2, U2.19 (TXRAMP)
unnamed: R16.2, U2.21 (GPIO0)
unnamed: R17.2, U2.22 (GPIO1)
unnamed: R18.2, U2.10 (GPIO2)
unnamed: R19.2, U2.11 (GPIO3)
unnamed: U2.2 (XTAL4), Y1.1
unnamed: U2.3 (XTAL3), Y1.2
unnamed: U2.7 (XOUT), Y2.3
unnamed: U2.8 (XIN), Y2.1
VCC: C1.1, C2.1, D1.1 (K), J1.3 (4), J1.4, U1.3 (IN)

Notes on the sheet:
POWER INPUT
Component values are optimised for 433MHz
MOUNTING HOLES

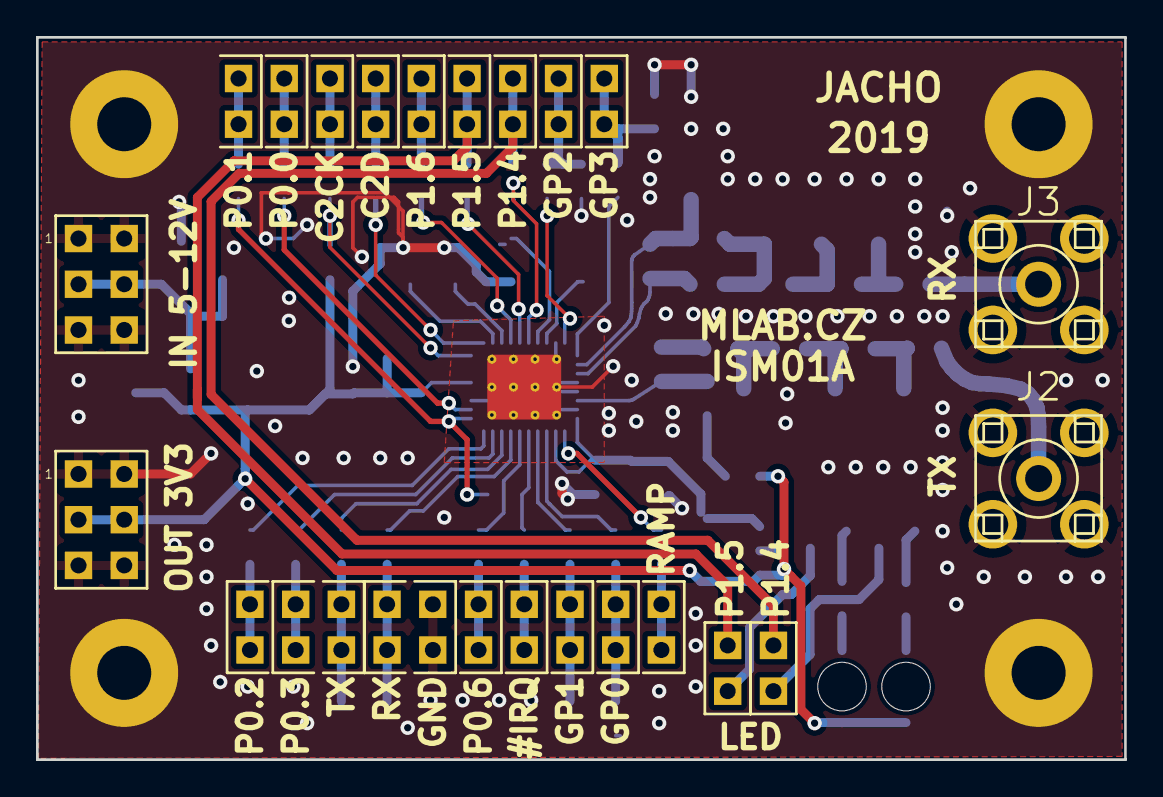
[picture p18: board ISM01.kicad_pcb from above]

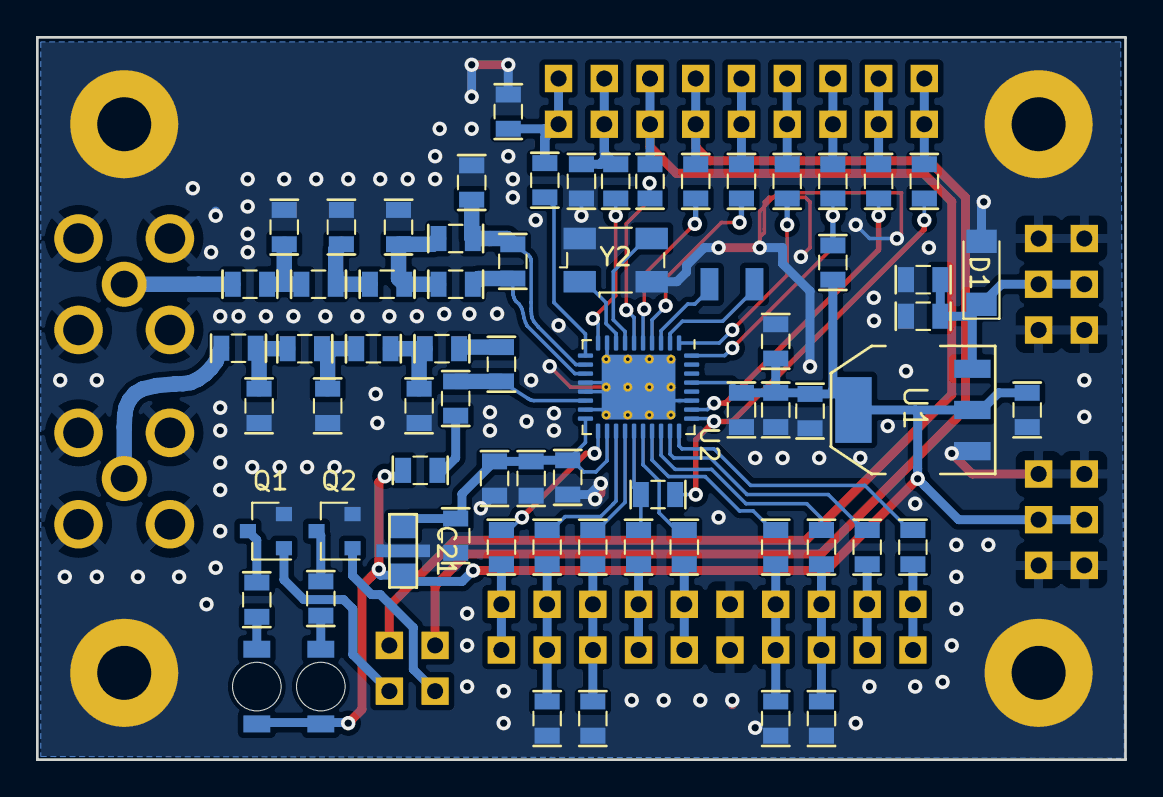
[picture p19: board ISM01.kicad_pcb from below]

Board: 2 copper layers, 60.5 x 40.1 mm, 98 parts (69 on the bottom side), 63 nets.

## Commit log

2018-11-29 [MLABweb] Documentaion edits; ISM01A
    [ISM01A.kicad_pcb, ISM01A.sch]
2019-02-19 Pokus o zaoblení RF cesty.
    [ISM01A.kicad_pcb]
2019-02-20 Zakulacení RF cest.
    [ISM01A.kicad_pcb]
2019-02-20 Vyrovnání izolačních mezer cest.
    [ISM01A.kicad_pcb]
2020-11-04 Edit 3D model
    [ISM01A.kicad_pcb]
2022-01-13 Adding a link to datasheet.
    [ISM01A.kicad_sch]
2022-04-06 Update actions products
    [ISM01A-B_Courtyard.dxf, ISM01A-B_Cu.dxf, ISM01A-B_Fab.dxf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]
2023-07-05 automated commit; rename source files to new naming convence
    [ISM01.kicad_pcb, ISM01.kicad_sch]
2023-07-20 aktualizace na kicad 7
    [ISM01.kicad_pcb, ISM01.kicad_sch, ISM01A.sch]
2025-02-03 Update project to KiCADv8.
    Fix wrong title block description.
    [ISM01.kicad_pcb, ISM01.kicad_sch]
